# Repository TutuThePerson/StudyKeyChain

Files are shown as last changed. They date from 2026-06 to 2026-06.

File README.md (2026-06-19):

# Study Pal
A small-portable study companion that motivates you to study!!! (probably). Its purpose is to play voice clips (initially in my own voice lol, but you could ask your teacher's voice), it aims to run fixed focus session and reminds you to take a break and hyrdrate all in the formfactor of a keychain.

## Why did I build this?

No clue. jk. I just finished 2 months of A-levels and being grinding those past papers for atleast half a year now; I realise it is really demoralising to be studying 3 in the morning alone - so this idea stemmed from those experiences. It's just a bit of fun really and isn't aimed as a full replacement for regular discipline and proper revision but might provide that **little** push to keep studying while staying healthy. I didn't want a big, bulky solution so I thought it would be cool if I could fit it on a keychain, that I could hang on my bag as such.
The StudyPal consists of a 2 layer PCB, larger than a regular keycap but still small enough to put in your pocket or hang on your bag. It runs an ESP32-S3, with audio functionality (physically hidden under the keycap)

## Functions:

1. It goes through focus sessions on variable length via the rotary encoder under the keycap.
2. It has audio playback through a speaker which aims to play motivational audio clips, session start-end cues and hydration reminders.
3. OLED display which shows timer, session stats and break progress througha slim slanted window on the keycap.
4. Keycap - short press for motivational cue, long press to end a session early or to power off
5. Hidden Rotary Encoder undeer the keycap to adjust session length
6. Battery powered via a single-cell LiPo with USB C charging and ESD protection

### Schematic:

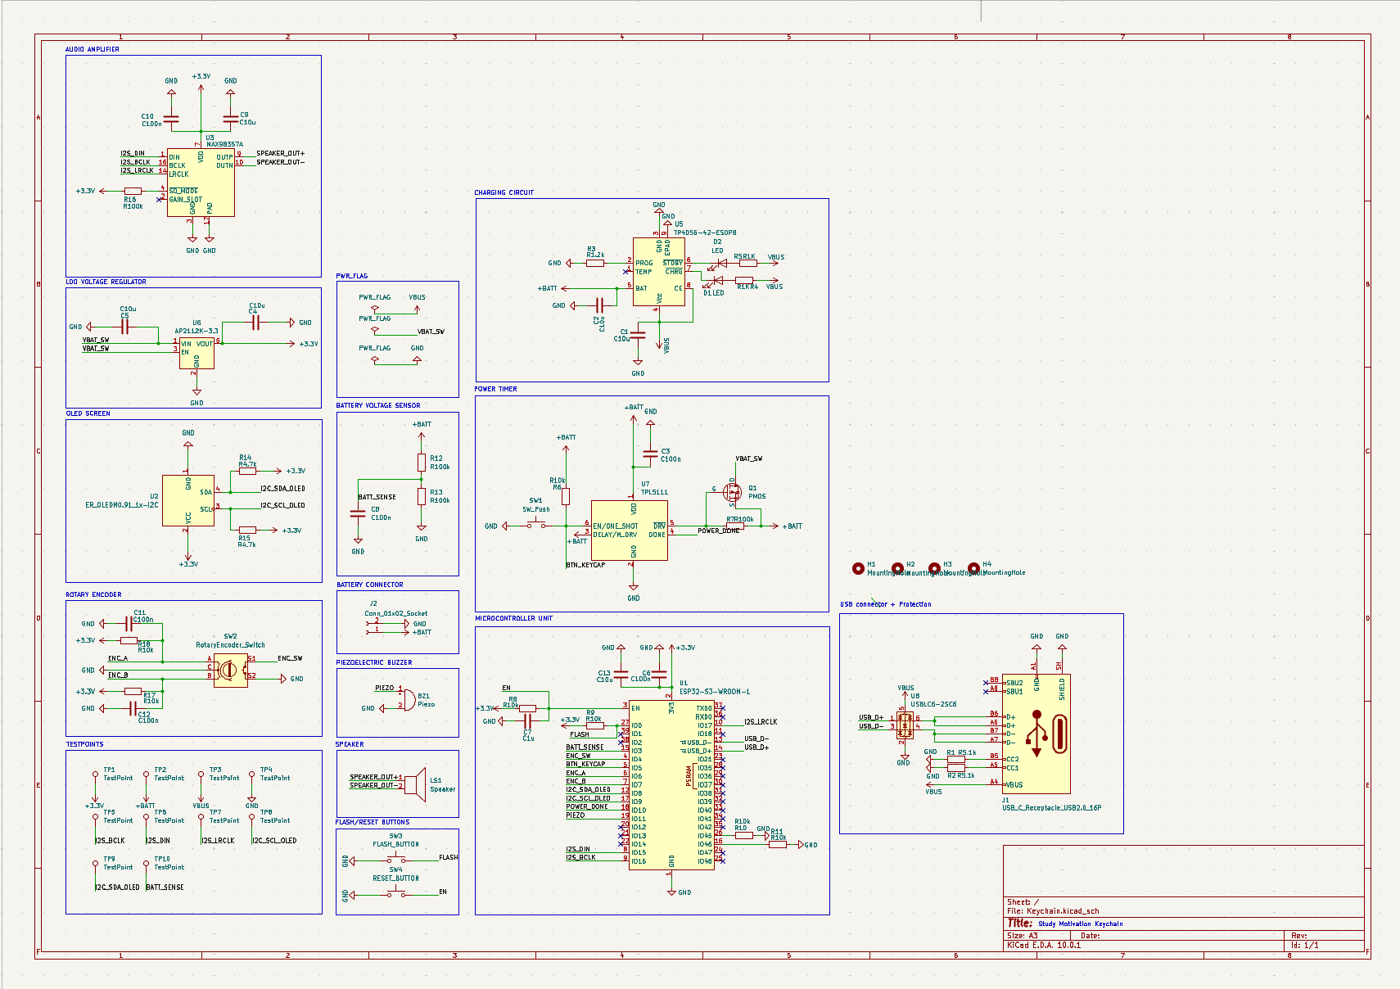
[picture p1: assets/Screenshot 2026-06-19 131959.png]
Schematic


### PCB:

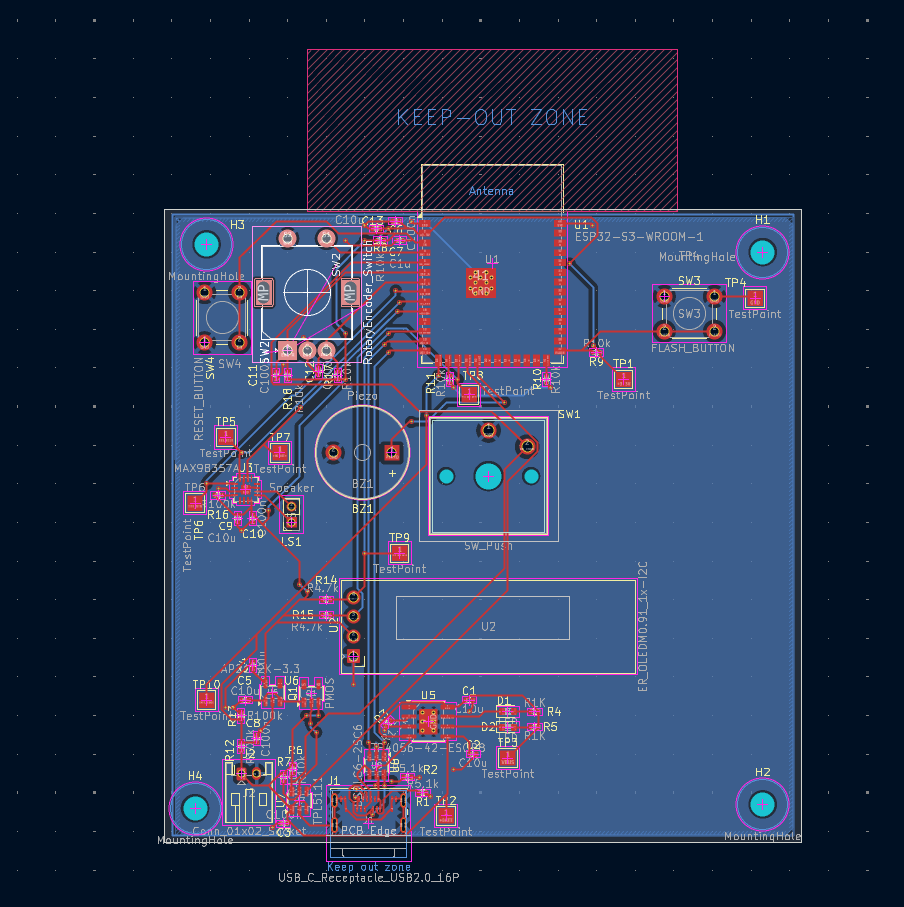
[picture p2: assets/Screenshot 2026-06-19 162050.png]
PCB kicad PCB

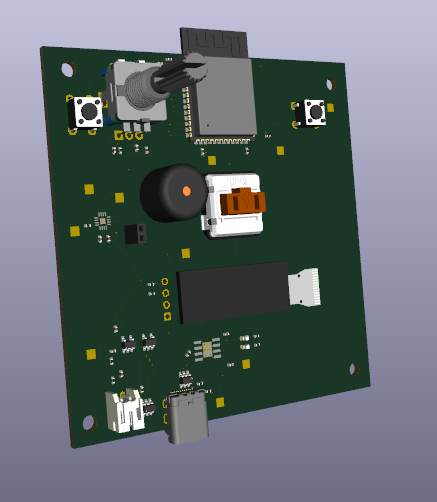
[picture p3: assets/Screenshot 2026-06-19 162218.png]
3D PCB kicad 3D RENDER PCB


### CASE:

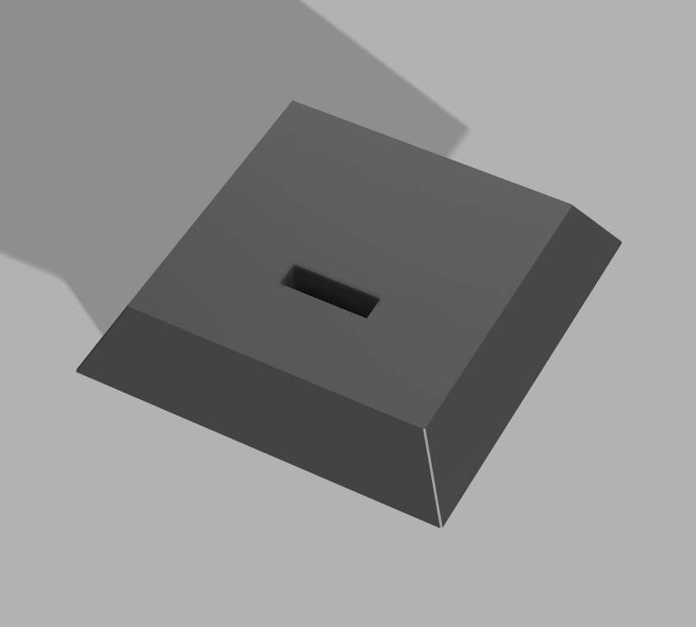
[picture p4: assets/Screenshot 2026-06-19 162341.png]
Assembled

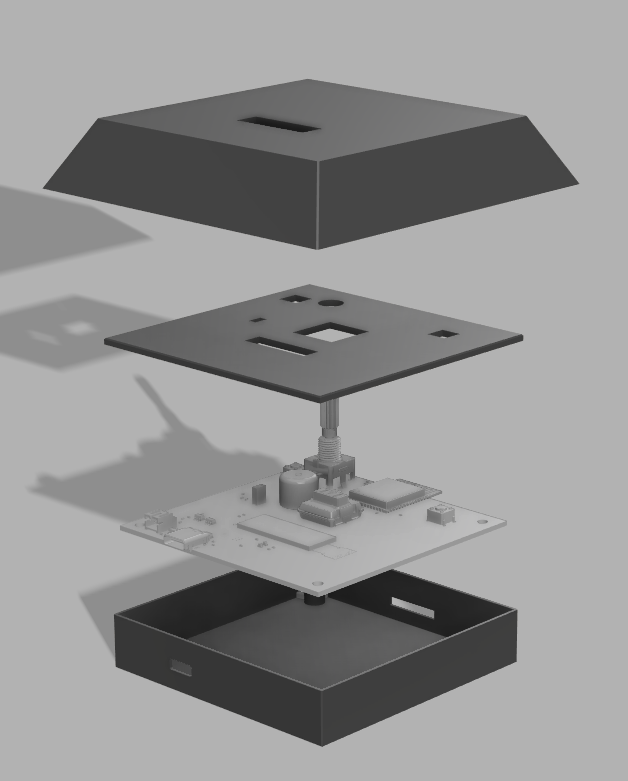
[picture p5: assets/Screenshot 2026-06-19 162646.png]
Exploded


### ZINE:

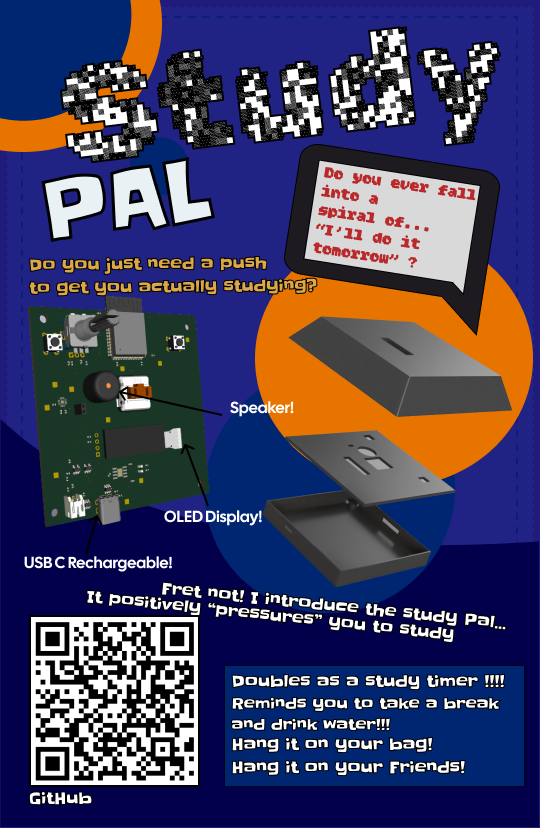
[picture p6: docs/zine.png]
Zine


## The Technical Stuff:

### Power sub-system:
 - USB-C in goes through TP4056 and manages LiPo charging at 1A (set by the 1200 ohm resistor). The charge status drives two LEDs where red = charging and green indicates fully charged/done. TPL5111 acts as a power switch by latching the AP2112k 3.3V LDO on when the user presses the Kalih  Choc Keycap, and cuts power when the firmware returns POWER_DONE.
 - A potential divider with 2 100k Ohm Resistor connectios is used to feed half the battery voltage so it can be read to monitor charge levels.

### Microcontroller unit
- ESP-32-S3-WROOM-1-N8, has 8 MB of flash, firmware and audio clips/message fit comfortably in the unit.
- The Strapping pins should be handled as stated by the datasheet.
   - GPIO0:10k pullup resistor and a flash button to GND
   - GPIO45/46: 10k pull down resistors to each pin
   - EN: 10k puullup with a 1 micro Farad Capacitor connected to ground in parallel.

### Audio:
- Audio is generated digitally by the microcontroller, and is streamed via I^2S to the class D amplifier, which in turn drives a speaked mounted under the keycap. Sound fires through the gapes just under the keycap edge.
- The amp's SD_MODE pin has a 100k ohm pullup to 3.3V, putting it in stereo mixed mono mode.

### Display: 
- 0.96" OLED breakouut connected via I^2C, viewed from a slim window cut into the case, meaning the display is stationary so it shouldn't be easily damaged.
- I^2C has 4.7k pullups to both SDA and SCL to 3.3V

### USB-C connector 
- 16 pin USB 2.0 receptable, D+ pads are tied together so directions works both ways - same goes for D- pads. These connections are then connected to the ESP32-S3's native USB pins. ESD protection is on both lines.

### PCB
- 2 layer
- L1 : components + signal traces
- L2 : ground pour and some signal traces

### Components:
1. ESP32-S3-WROOM-N8 MCU
2. TP4056 charging IC
3. TPL5111 power timer
4. AO3401 P-MOSFET
5. AP2122K - 3.3 LDO
6. MAX98357A audio amp
7. USBLC6-2SC6 ESD
8. USB-C connector 16-pin
9. 0.91" 128x32 SSD1306 OLED breakout
10. 28mm 8ohmn 2W speaker
11. 12mm piezo buzzer
12. Kalih Choc V1 Brown
13. EC11 Rotary Encoder
14. LiPo 803040 - 1000mah
15. Resistors (100k,10k,5.1k,4.7k,1.2k,1k - 0402)
16. Capacitors ( 100n,10u,1u = 0402)
17. LED (RED, GREEN - 0603)
18. 6mm tactile button
19. PCB
20. M3 self-tapping screws
21. 3D printed case + keycap

### BOM:
|No.|ITEM NAME|QUANTITY|UNIT PRICE|TOTAL PRICE|URL|
|-|-|-|-|-|-|
|1.|ESP32-S3-WROOM-1-N8|1|£4.21|£4.21|https://www.digikey.co.uk/en/products/detail/espressif-systems/ESP32-S3-WROOM-1-N8/15200089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|
|2.|TP4056 Charging IC|1|£1.00|£5.00 (pack of 5)|https://www.amazon.co.uk/TP4056-SOP-8-Chips-Battery-Charging-Black/dp/B0FKNDMF2P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|
|3.|TPL5111 power timer|1|£0.88|£0.88|https://www.digikey.co.uk/en/products/detail/texas-instruments/TPL5111DDCR/6572460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|
|4.|AO3401 P-MOSFET|1|£0.16|£0.16|https://www.digikey.co.uk/en/products/detail/umw/ao3401a/16705973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|
|5.|AP2112K-3.3 LDO|1|£0.19|£0.19|https://www.digikey.co.uk/en/products/detail/diodes-incorporated/AP2112K-3.3TRG1/4470746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|
|6.|MAX98357A AUDIO AMP|1|£2.77|£2.77|https://www.digikey.co.uk/en/products/detail/analog-devices-inc-maxim-integrated/max98357aete-t/4936122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|
|7.|USBLC6-2SC6 ESD|1|£0.33|£0.33|https://www.digikey.co.uk/en/products/detail/analog-devices-inc-maxim-integrated/max98357aete-t/4936122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|
|8.|USB-C connector 16 pin|1|£1.65|£1.65|https://www.digikey.co.uk/en/products/detail/amphenol-cs-commercial-products/124019772112A/13683231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|
|9.|0.96" SSD1306 OLED BREAKOUT|1|£1.49|£1.49|https://www.aliexpress.com/item/1005006782987637.html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|
|10.|28mm 8OHM 2W speaker|1|£0.17|£0.99 (pack of 6|https://www.aliexpress.com/item/1005011990029265.html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|
|11.|12mm PIEZO BUZZER|1|£0.05|£0.99 (pack of 20)|https://www.aliexpress.com/item/1005009235440867.html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|
|12.|Kalih Choc V1|1|£0.35|£3.48( pack of 10)|https://www.aliexpress.com/item/1005011812362132.html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|
|13.|EC11 Rotary Encoder|1|£0.90|£0.90|https://www.aliexpress.com/item/1005007644083514.html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|
|14.|LiPo 803040 -1000mah|1|£3.79|£3.79|https://www.aliexpress.com/item/1005011940576057.html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|
|15.| Resistor 100k|4|£0.07|£0.28|https://www.digikey.co.uk/en/products/detail/yageo/RC0402FR-07100KL/726526|
|16.| Resistor 10k| 7|£0.07|£0.49|https://www.digikey.co.uk/en/products/detail/yageo/RC0402FR-0710KL/726523|
|17.| Resistor 5.1k|2|£0.07|£0.14|https://www.digikey.co.uk/en/products/detail/yageo/RC0402FR-075KL/5917711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|
|18.| Resistor 4.7k|2|£0.07|£0.14|https://www.digikey.co.uk/en/products/detail/yageo/RC0402FR-074K7L/2827563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|
|19.| Resistor 1.2k|1|£0.07|£0.07|https://www.digikey.co.uk/en/products/detail/yageo/RC0402FR-071K2L/726517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|
|20.| Resistor 1k|2|£0.07|£0.14|https://www.digikey.co.uk/en/products/detail/yageo/RC0402FR-071KL/726513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|
|21.| Capacitor 10u|6|£0.27|£1.62|https://www.digikey.co.uk/en/products/detail/murata-electronics/GRM155R61A106ME18D/26264983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|
|22.| Capacitor 1u|1|£0.07|£0.07|https://www.digikey.co.uk/en/products/detail/taiyo-yuden/JMK105BJ105KV-F/930583|
|23.| Capacitor 100n|6|£0.07|£0.42|https://www.digikey.co.uk/en/products/detail/samsung-electro-mechanics/CL05B104KP5NNNC/3886660|
|24.| LED RED|1|£0.34|£0.34|https://www.digikey.co.uk/en/products/detail/lumex-opto-components-inc/SML-LXFM0603SIC-TR/411897|
|25.| LED GREEN|1|£0.25|£0.25|https://www.digikey.co.uk/en/products/detail/w%C3%BCrth-elektronik/150060GS73220/8557160|
|26.| 6mm Tactile Button|2|£0.87|£1.74|https://www.digikey.co.uk/en/products/detail/omron-electronics-inc-emc-div/B3U-1100P/1534339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|
|27.|PCB|1|£0.48|£2.4|JLCPCB|
|28.|Solder Paste Stencil|1|£5.37|£5.37|JLCPCB|
|29.|M3 Self Tapping Screws|4|£0.05|£2.47(50pack)|https://cpc.farnell.com/unbranded/m3x6-pan-pozi-stainl/m3x6-pan-pozi-stainless-screws/dp/FN00814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|pcrid|426684131423|kword||match||plid||slid||product|FN00814|pgrid|100371162718|ptaid|pla-2177230439981|&CMP=KNC-GUK-CPC-SHOPPING-9262013734-100371162718-FN00814&s_kwcid=AL!5616!3!426684131423!!!network}!2177230439981!&gad_source=1&gad_campaignid=9262013734&gbraid=0AAAAAD_m6B18mbvSishqdH_AlczsMH5Ge&gclid=CjwKCAjw0dPRBhAPEiwAE5vTToLz2cqZ-4VV0NWd0TadiM0KJ0ZQb9aNZPIKNwyf5dgqHOcgOcoShBoCqskQAvD_BwE
|30.|3D printed Case and Keycap|1 set|N/A (small)|£10.50 (1 Roll PETG HF)|https://uk.store.bambulab.com/products/petg-hf?id=42010450264124|
|31.|Thin Wire|1|~£0.5 (1m)|£4.99 (spool of 10m)|https://www.amazon.co.uk/sourcing-map-Stranded-Electrical-Connecting/dp/B0F6LRFJS6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|
|32.|Keychain|1|£0.13|£3.89 (pack of 30)|https://www.amazon.co.uk/YHYZ-Premium-Keychain-Suitable-Jewelry/dp/B08CMWFL8Y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|
-
### Assembly:
 - Make sure you have all components listed available and casing 3D printed.
 - Solder all the components on the PCB as per the schematic
 - Connect the battery to the 2 pin connector (label in schematic file)
 - Place the PCB on top of the base and use M3 screws, preferably around 3-4mm
 - Flash firmware onto the ESP32 using the USB-C connector (If there is no output when flashing, hold the flash button to reset - forces chip into download mode)
 - Use plastic adhesive to adhere the the lid to the base - once everything works okay
 - Put on the keycap and enjoy!

### Design Notes:
- You could go with a different mcu but I chose the ESP-32 as this one has native USB, decent peripheral support and has 8MB of memory which makes it a suitable cost-effective solution in this case. The atenna is not used, but it could be used in future alterations with firmware but if you really wanted bluetooth or wifi you can use ur phone lol
- I reccomend you get a stencil which would make soldering alot easier
- The system switches and the rotary encoder is located under the keycap as they are designed to be set-once parameters, not designed to be constantly adjusted so this would make the keycap look better.

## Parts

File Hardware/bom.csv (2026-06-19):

No | ITEM NAME | QUANTITY | UNIT PRICE | TOTAL PRICE
1 | ESP32-S3-WROOM-1-N8 | 1 | £4.21 | £4.21
2 | TP4056 | Charging IC | 1 | £1.00 | £5.00
3 | TPL5111 power timer | 1 | £0.88 | £0.88
4 | AO3401 P-MOSFET | 1 | £0.16 | £0.16
5 | AP2112K-3.3 LDO | 1 | £0.19 | £0.19
6 | MAX98357A AUDIO AMP | 1 | £2.77 | £2.77
7 | USBLC6-2SC6 ESD | 1 | £0.33 | £0.33
8 | USB-C connector 16 pin | 1 | £1.65 | £1.65
9 | 0.96" SSD1306 OLED BREAKOUT | 1 | £1.49 | £1.49
10 | 28mm 8OHM 2W speaker | 1 | £0.17 | £0.99
11 | 12mm PIEZO BUZZER | 1 | £0.05 | £0.99
12 | Kalih Choc V1 | 1 | £0.35 | £3.48
13 | EC11 Rotary Encoder | 1 | £0.90 | £0.90
14 | LiPo 803040 -1000mah | 1 | £3.79 | £3.79
15 | Resistor 100k | 1 | £0.07 | £0.28
16 | Resistor 10k | 7 | £0.07 | £0.49
17 | Resistor 5.1k | 2 | £0.07 | £0.14
18 | Resistor 4.7k | 2 | £0.07 | £0.14
19 | Resistor 1.2k | 1 | £0.07 | £0.07
20 | Resistor 1k | 2 | £0.07 | £0.14
21 | Capacitor 10u | 6 | £0.27 | £1.62
22 | Capacitor 1u | 1 | £0.07 | £0.07
23 | Capacitor 100n | 6 | £0.07 | £0.42
24 | LED RED | 1 | £0.34 | £0.34
25 | LED GREEN | 1 | £0.25 | £0.25
26 | 6mm Tactile Button | 2 | £0.87 | £1.74
27 | PCB | 1 | £0.48 | £2.40
28 | Solder Paste Stencil | 1 | £5.37 | £5.37
29 | M3 Self Tapping Screws | 4 | £0.05 | £2.47
30 | 3D printed Case and Keycap | 1 | setn/a (small) | £10.50
31 | Thin Wire | 1 | ~£0.5 | £4.99
32 | Keychain | 1 | £0.13 | £3.89

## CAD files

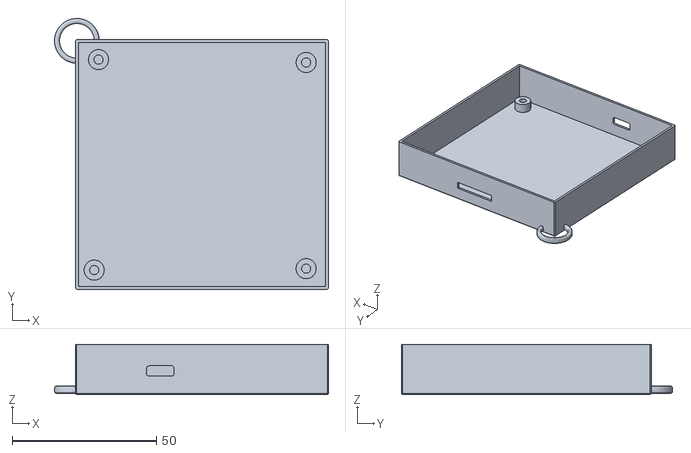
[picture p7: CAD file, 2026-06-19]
Case/main_case_body.stl
95.0 x 94.0 x 17.5

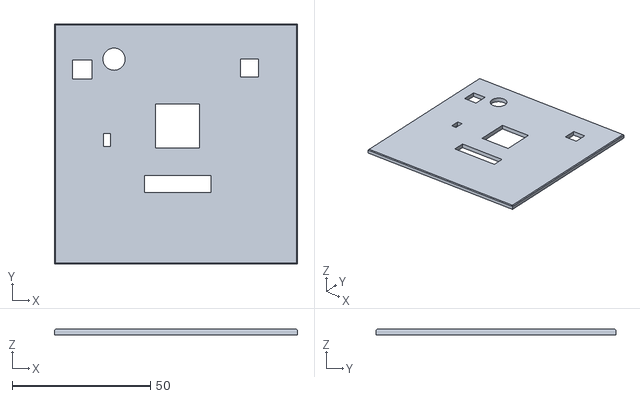
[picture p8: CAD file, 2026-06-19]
Case/main_body_lid.stl
87.7 x 86.7 x 2.00

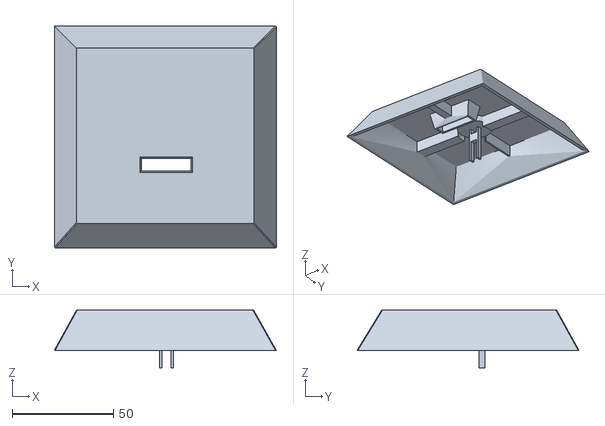
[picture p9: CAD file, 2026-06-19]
Case/keycap.stl
109.8 x 110.0 x 28.5

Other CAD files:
Case/Keychain_Casing_Source.f3d

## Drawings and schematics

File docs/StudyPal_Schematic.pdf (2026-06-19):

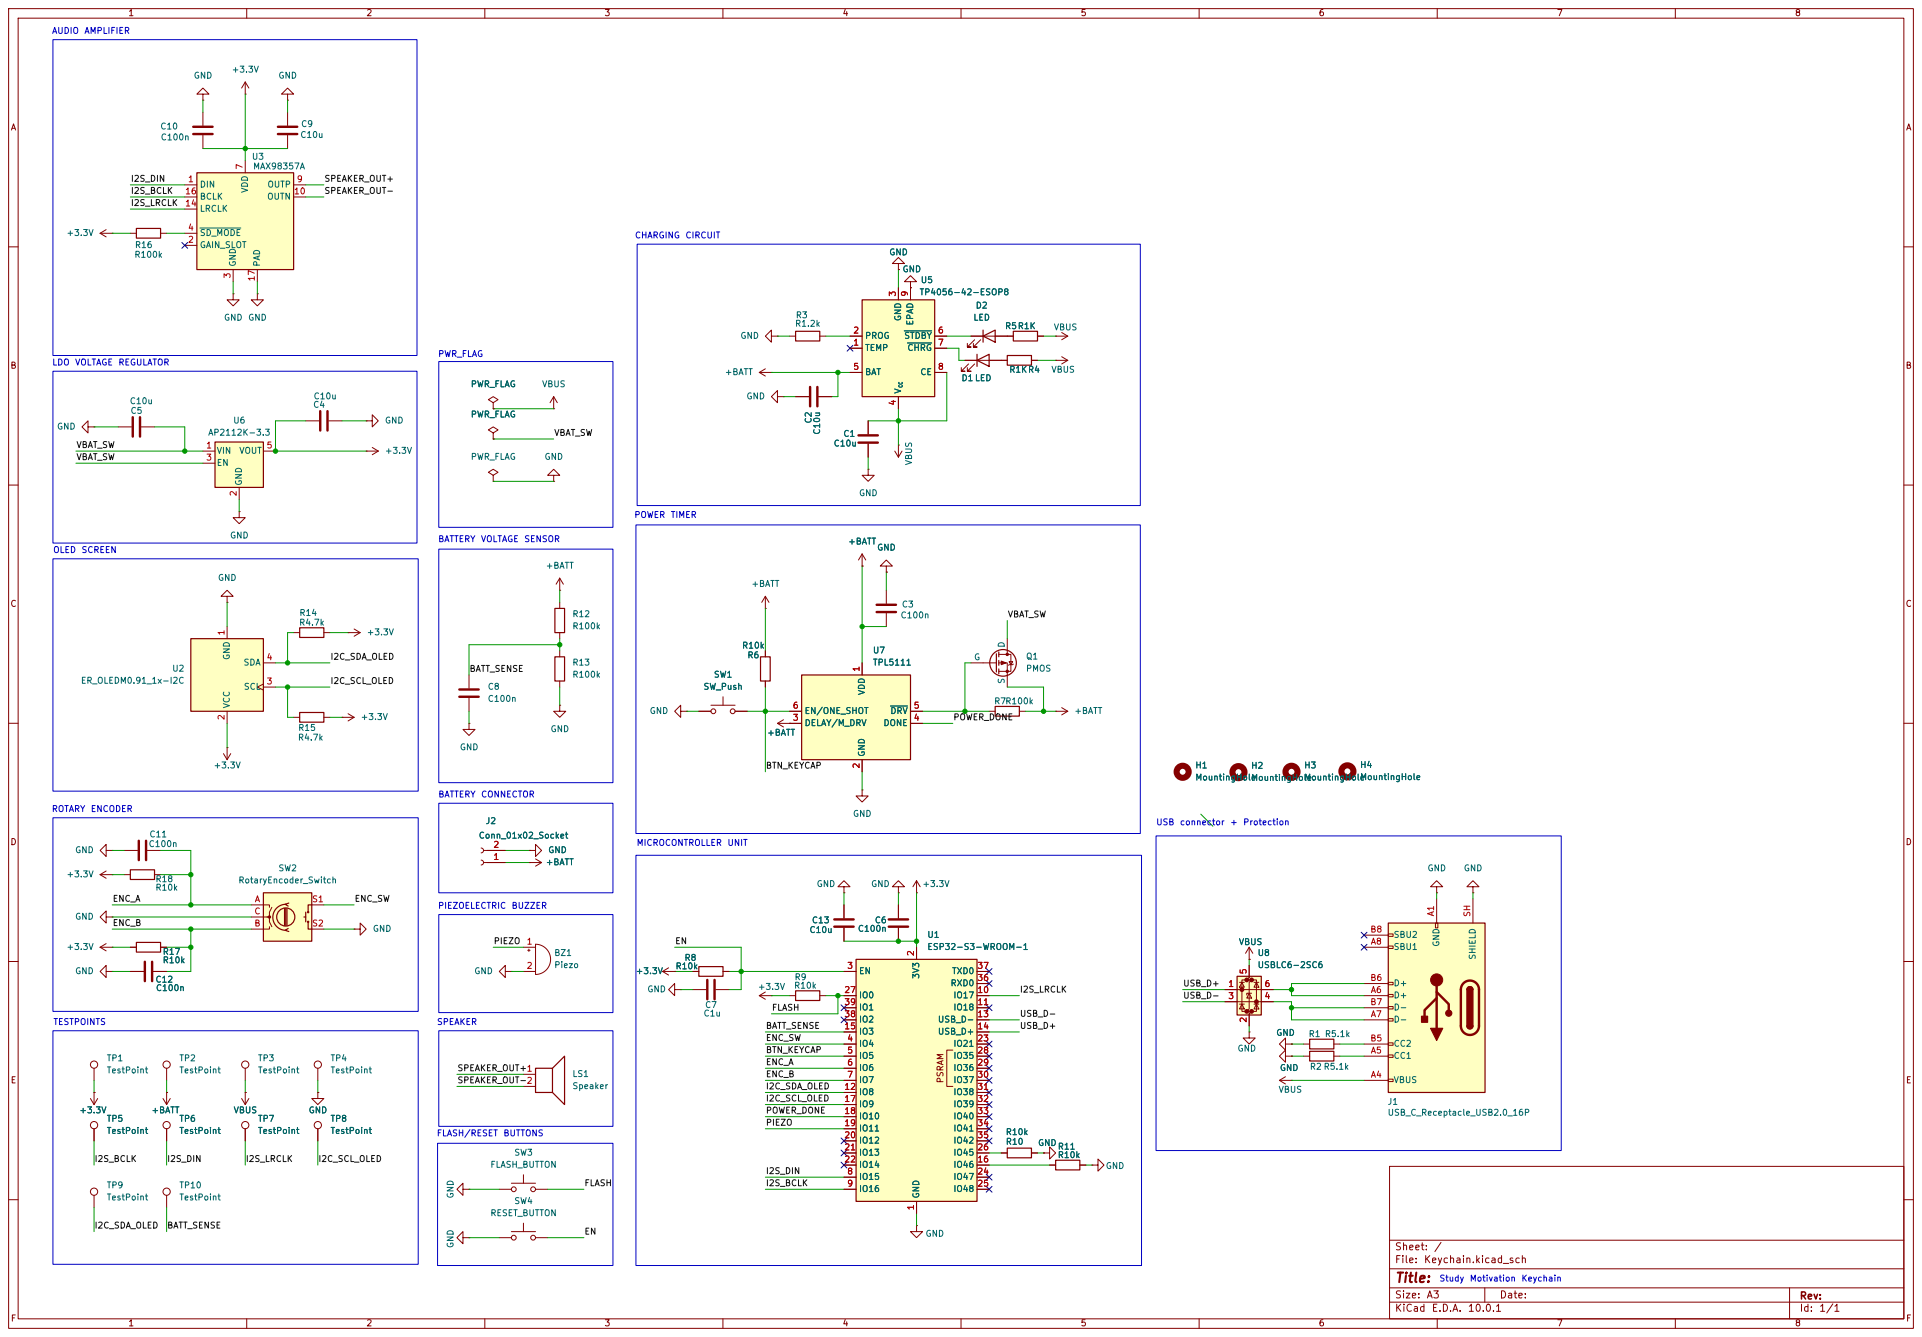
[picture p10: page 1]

LDO VOLTAGE REGULATOR OLED SCREEN

PIEZO

VBUS A4 CC1 A5 D+ A6 D- A7

Size: A3 | Rev:
KiCad E.D.A. 10.0.1 | Id: 1/1

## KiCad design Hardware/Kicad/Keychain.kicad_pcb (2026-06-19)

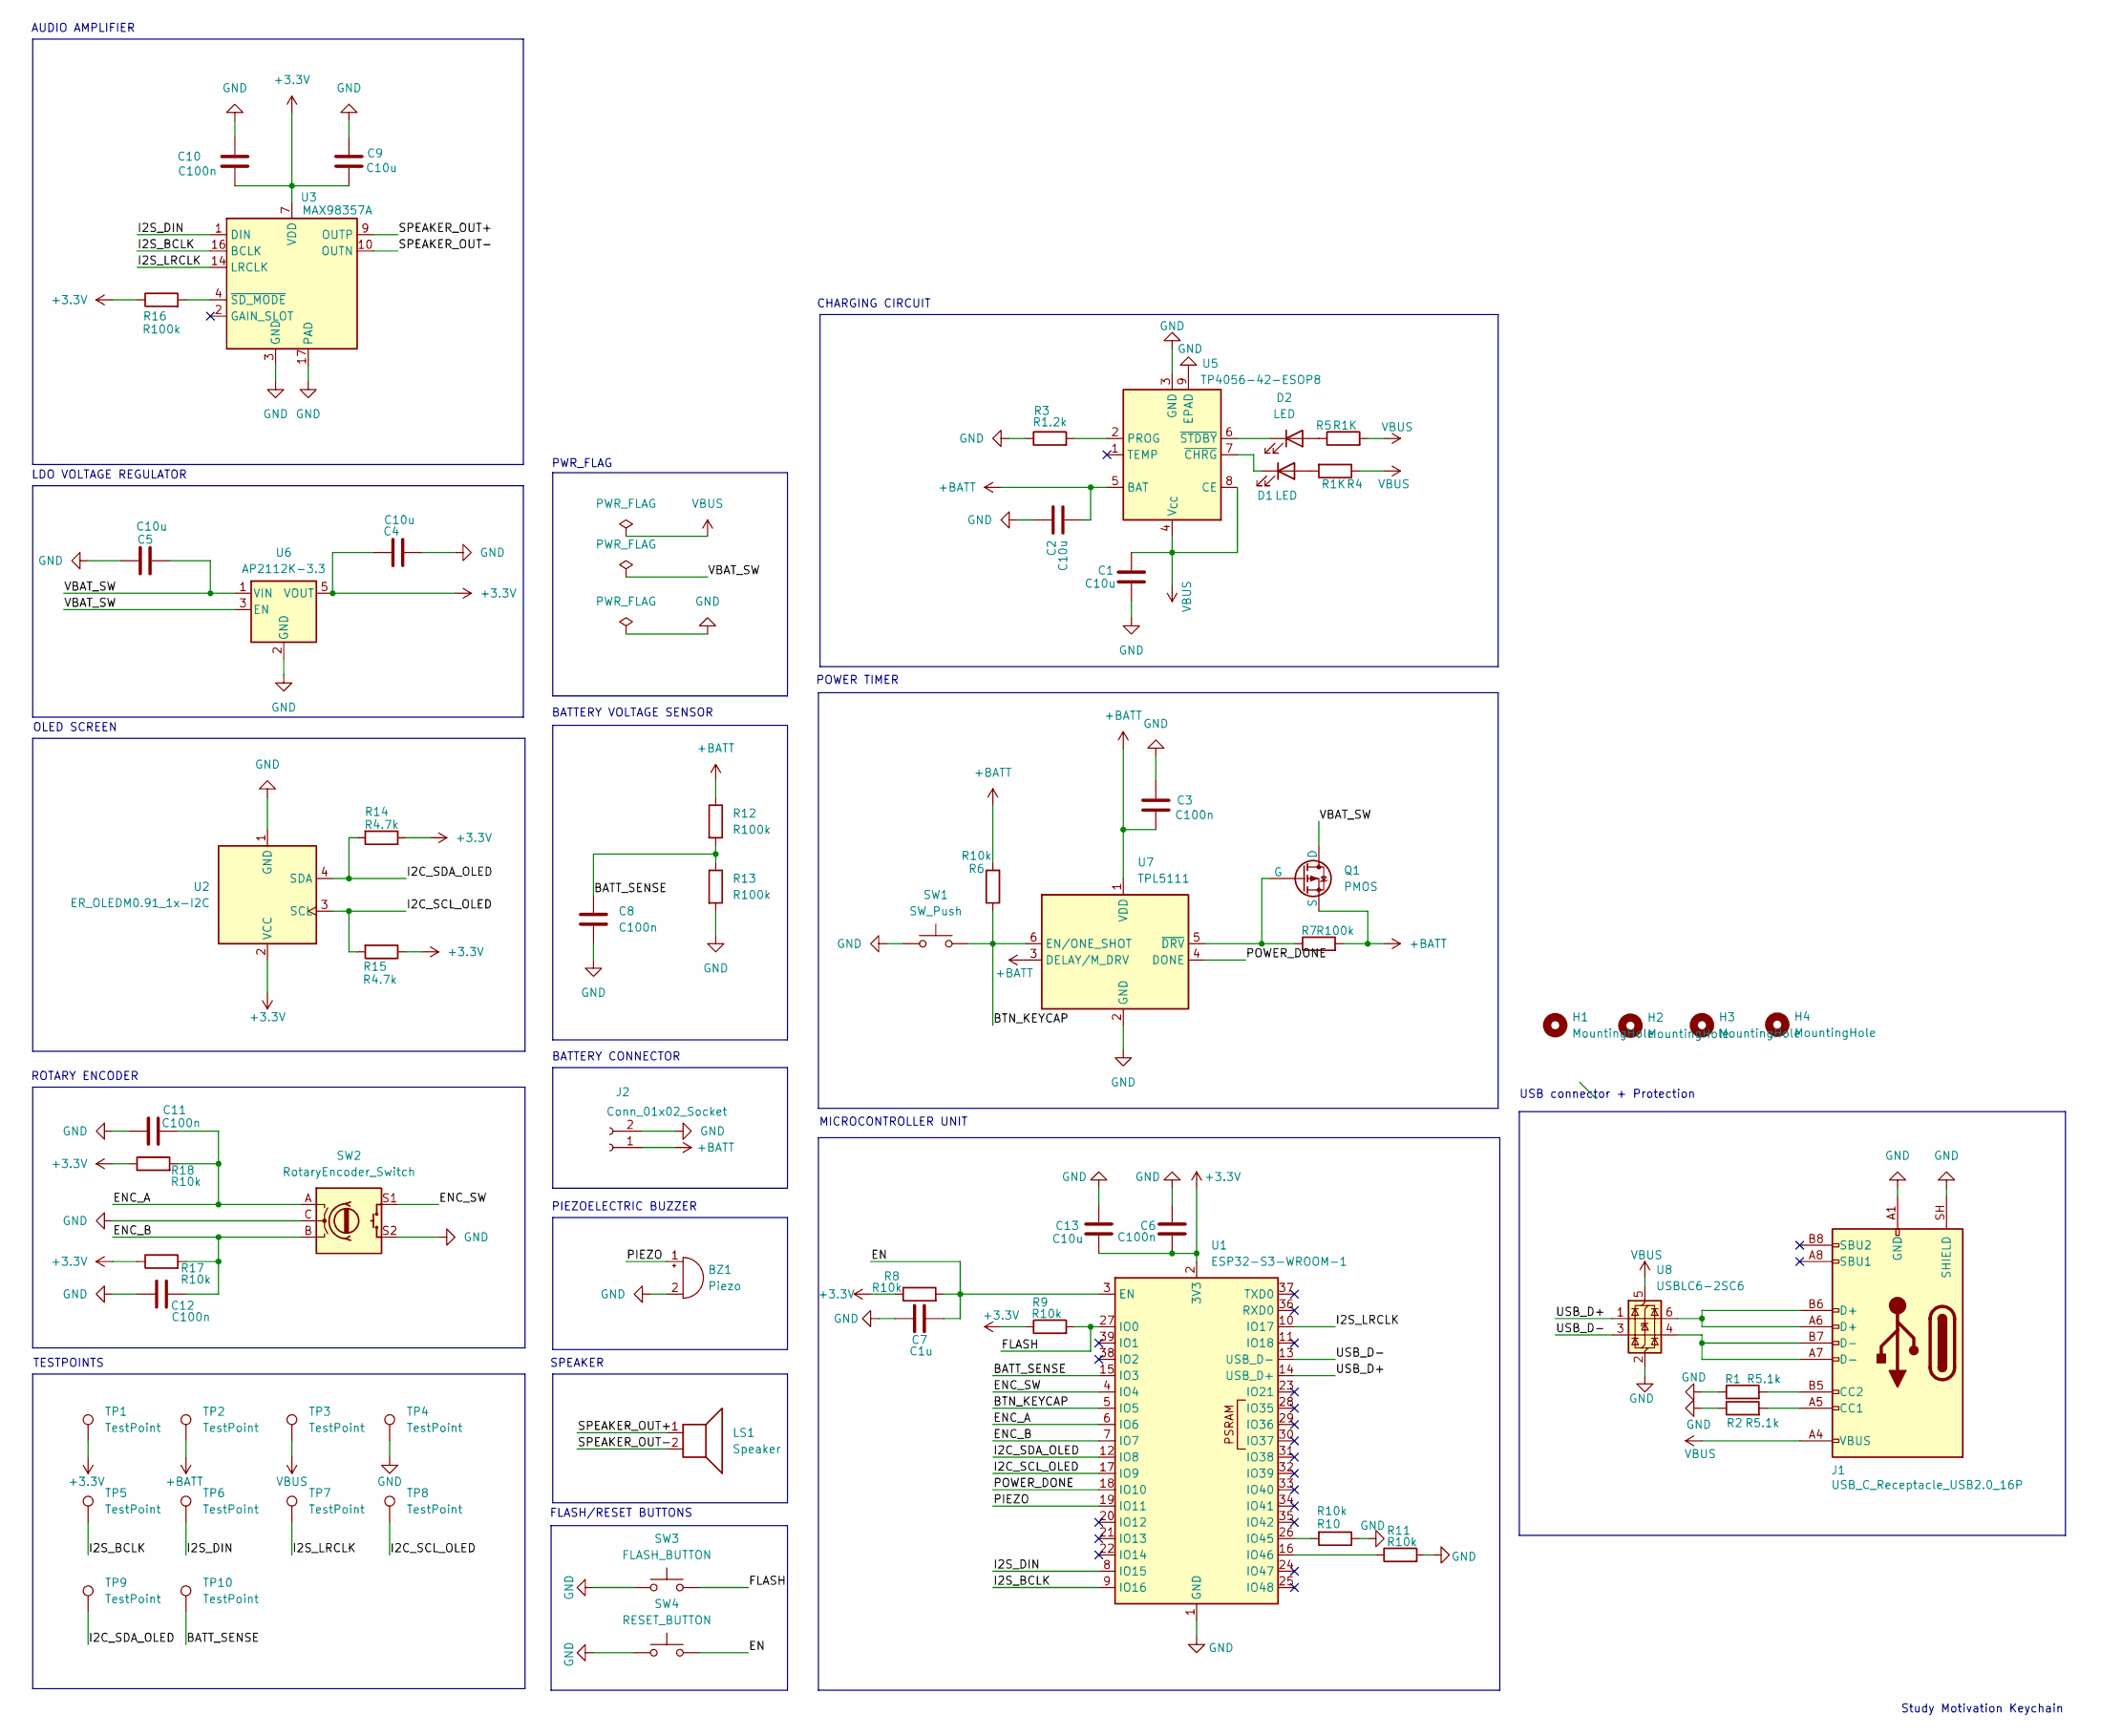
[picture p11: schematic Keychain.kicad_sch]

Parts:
BZ1: Piezo; Buzzer_12x9.5RM7.6
C1, C2, C4, C5, C9, C13: C10u; C_0402_1005Metric
C3, C6, C8, C10, C11, C12: C100n; C_0402_1005Metric
C7: C1u; C_0402_1005Metric
D1, D2: LED; LED_0603_1608Metric
H1, H2, H3, H4: MountingHole; MountingHole_3.2mm_M3
J1: USB_C_Receptacle_USB2.0_16P; USB_C_Receptacle_Amphenol_124019772112A
J2: Conn_01x02_Socket; JST_PH_S2B-PH-K_1x02_P2.00mm_Horizontal
LS1: Speaker; PinSocket_1x02_P2.00mm_Vertical
Q1: PMOS; SOT-23-5
R1, R2: R5.1k; R_0402_1005Metric
R3: R1.2k; R_0402_1005Metric
R4, R5: R1K; R_0402_1005Metric
R6, R8, R9, R10, R11, R17, R18: R10k; R_0402_1005Metric
R7, R12, R13, R16: R100k; R_0402_1005Metric
R14, R15: R4.7k; R_0402_1005Metric
SW1: SW_Push; SW_Kailh_Choc_V1_1.00u
SW2: RotaryEncoder_Switch; RotaryEncoder_Alps_EC11E-Switch_Vertical_H20mm
SW3: FLASH_BUTTON; SW_PUSH_6mm
SW4: RESET_BUTTON; SW_PUSH_6mm
TP1, TP2, TP3, TP4, TP5, TP6, TP7, TP8, TP9, TP10: TestPoint; TestPoint_Pad_2.0x2.0mm
U1: ESP32-S3-WROOM-1
U2: ER_OLEDM0.91_1x-I2C
U3: MAX98357A; TQFN-16-1EP_3x3mm_P0.5mm_EP1.23x1.23mm
U5: TP4056-42-ESOP8; SOIC-8-1EP_3.9x4.9mm_P1.27mm_EP2.41x3.3mm_ThermalVias
U6: AP2112K-3.3; SOT-23-5
U7: TPL5111; SOT-23-6
U8: USBLC6-2SC6; SOT-23-6

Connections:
+3.3V: C4.1, C6.1, C9.2, C10.2, C13.1, R8.1, R9.1, R14.1, R15.1, R16.1, R17.1, R18.1, TP1.1 (1_1), U1.2 (3V3), U2.2 (VCC), U3.7 (VDD), U3.8 (VDD), U6.5 (VOUT)
+BATT: C2.1, C3.1, J2.1, Q1.3 (S), R6.2, R7.2, R12.1, TP2.1 (1_1), U5.5 (BAT), U7.1 (VDD), U7.3 (DELAY/M_DRV)
/<NO NET>: TP7.1 (1_1), U1.10 (IO17), U3.14 (LRCLK)
/BATT_SENSE: C8.1, R12.2, R13.1, TP10.1 (1_1), U1.15 (IO3)
/BTN_KEYCAP: R6.1, SW1.2, U1.5 (IO5), U7.6 (EN/ONE_SHOT)
/EN: C7.2, R8.2, SW4.2, U1.3 (EN)
/ENC_A: C11.2, R18.2, SW2.A, U1.6 (IO6)
/ENC_B: C12.2, R17.2, SW2.B, U1.7 (IO7)
/ENC_SW: SW2.S1, U1.4 (IO4)
/FLASH: R9.2, SW3.2, U1.27 (IO0)
/I2C_SCL_OLED: R15.2, TP8.1 (1_1), U1.17 (IO9), U2.3 (SCL)
/I2C_SDA_OLED: R14.2, TP9.1 (1_1), U1.12 (IO8), U2.4 (SDA)
/I2S_BCLK: TP5.1 (1_1), U1.9 (IO16), U3.16 (BCLK)
/I2S_DIN: TP6.1 (1_1), U1.8 (IO15), U3.1 (DIN)
/PIEZO: BZ1.1 (+), U1.19 (IO11)
/POWER_DONE: U1.18 (IO10), U7.4 (DONE)
/SPEAKER_OUT+: LS1.1, U3.9 (OUTP)
/SPEAKER_OUT-: LS1.2, U3.10 (OUTN)
/USB_D+: U1.14 (USB_D+), U8.1 (I/O1)
/USB_D-: U1.13 (USB_D-), U8.3 (I/O2)
/VBAT_SW: C5.1, Q1.1 (D), U6.1 (VIN), U6.3 (EN)
GND: BZ1.2 (-), C1.2, C2.2, C3.2, C4.2, C5.2, C6.2, C7.1, C8.2, C9.1, C10.1, C11.1, C12.1, C13.2, J1.A1 (GND), J1.A12 (GND), J1.B1 (GND), J1.B12 (GND), J1.SH (SHIELD), J2.2, R1.1, R2.1, R3.1, R10.1, R11.2, R13.2, SW1.1, SW2.C, SW2.S2, SW3.1, SW4.1, TP4.1 (1_1), U1.1 (GND), U1.40 (GND), U1.41 (GND), U2.1 (GND), U3.3 (GND), U3.11 (GND), U3.15 (GND), U3.17 (PAD), U5.3 (GND), U5.9 (EPAD), U6.2 (GND), U7.2 (GND), U8.2 (GND)
unnamed: D1.2 (A), R4.2
unnamed: D1.1 (K), U5.7 (~CHRG)
unnamed: D2.2 (A), R5.1
unnamed: D2.1 (K), U5.6 (~STDBY)
unnamed: J1.A5 (CC1), R2.2
unnamed: J1.B5 (CC2), R1.2
unnamed: J1.A6 (D+), J1.B6 (D+), U8.6 (I/O1)
unnamed: J1.A7 (D-), J1.B7 (D-), U8.4 (I/O2)
unnamed: Q1.2 (G), R7.1, U7.5 (~DRV)
unnamed: R10.2, U1.26 (IO45)
unnamed: R11.1, U1.16 (IO46)
unnamed: R16.2, U3.4 (~SD_MODE)
unnamed: R3.2, U5.2 (PROG)
VBUS: C1.1, J1.A4 (VBUS), J1.A9 (VBUS), J1.B4 (VBUS), J1.B9 (VBUS), R4.1, R5.2, TP3.1 (1_1), U5.4 (V_{CC}), U5.8 (CE), U8.5 (VBUS)

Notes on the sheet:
LDO VOLTAGE REGULATOR
TESTPOINTS
ROTARY ENCODER
POWER TIMER
MICROCONTROLLER UNIT
PIEZOELECTRIC BUZZER
BATTERY CONNECTOR
SPEAKER
FLASH/RESET BUTTONS
Study Motivation Keychain
PWR_FLAG
AUDIO AMPLIFIER
BATTERY VOLTAGE SENSOR
OLED SCREEN
CHARGING CIRCUIT
USB connector + Protection

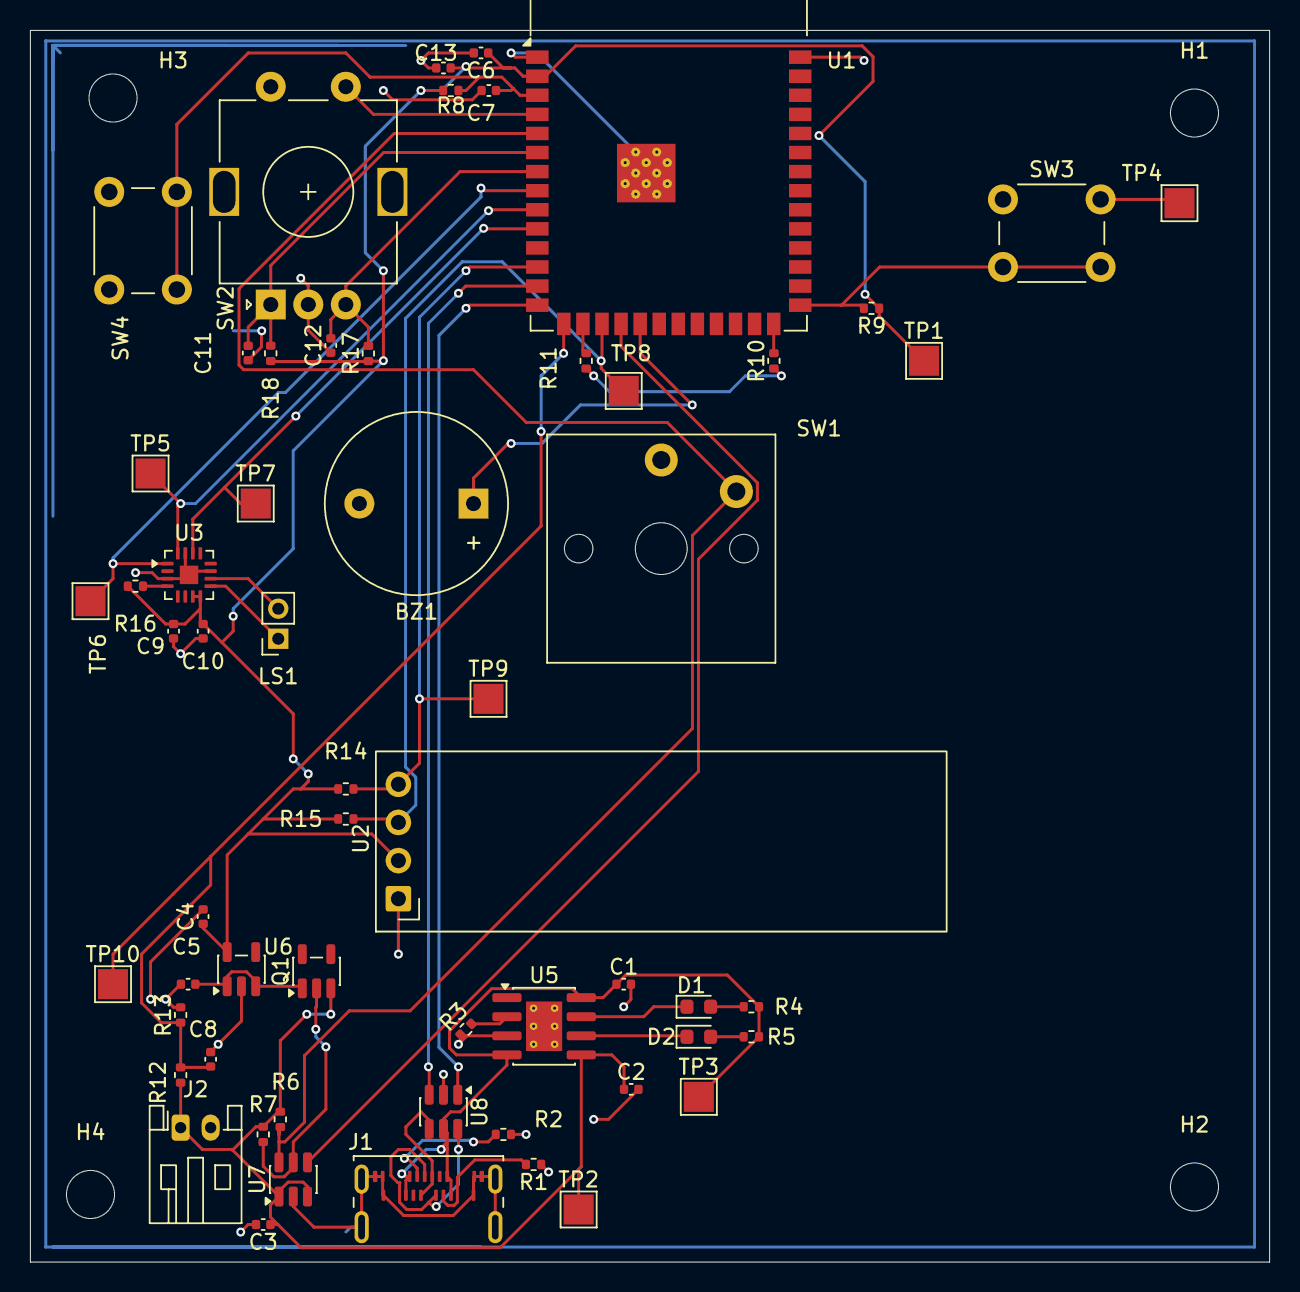
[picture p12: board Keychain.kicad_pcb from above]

Board: 2 copper layers, 82.5 x 82.0 mm, 63 parts (0 on the bottom side), 36 nets.

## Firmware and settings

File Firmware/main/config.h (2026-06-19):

#pragma once

//#############
// This file contains the pin assignments for the study keychain project
//#############

// Button (Kalih Choc Switch)
#define PIN_BUTTON 5

// Rotary encoder
#define PIN_ENCODER_A 6
#define PIN_ENCODER_B 7
#define PIN_ENCODER_SW 4 

//I^2C (Oled Display)
#define PIN_i2C_SDA 12
#define PIN_i2C_SCL 17
#define I2C_FREQ_HZ 400000
#define OLED_ADDRESS 0x3C

// I^2S (audio amplifier)
#define PIN_I2S_DIN 8
#define PIN_I2S_BCLK 9
#define PIN_I2S_LRCLK 10

// Piezoelectric (audio feedback)
#define PIN_PIEZO 11

// Power Management 
#define PIN_POWER_DONE 18
#define PIN_BATTERY_SENS 15

//#############
//constants
//#############

//Study Session Duration (fixed)

#define SESSION_DEFAULT_SECONDS 3300
#define BREAK_DURATION_SECONDS 300

//Reminder

#define HYDRATION_REMINDER_SECONDS 3300

// Battery Monitoring
#define POTENTIAL_DIVIDER_RATIO 2.0f 
#define FULL_BATT_mV 4200
#define BATT_EMPTY_mV 3000
#define BATT_LOW_mV 3300

// Audio 
#define I2S_SAMPLE_RATE 16000 
#define I2S_BUFFER_SIZE 1024

// other UI/timing
#define IDLE_TIMEOUT_mS 30000
#define POWER_OFF_TIMEOUT_mS 14400000
#define LONG_PRESS_mS 2000
#define DEBOUNCE_mS 30

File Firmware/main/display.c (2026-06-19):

#include "display.h"
#include "config.h"
#include "driver/i2c.h"
#include "esp_log.h"
#include "freertos/FreeRTOS.h"
#include "freertos/task.h"
#include <string.h>
#include <stdio.h>
#include "font8x8.h"

static const char *TAG = "DISPLAY";

#define DISPLAY_OFF 0xAE
#define DISPLAY_ON 0xAF
#define SET_PAGE 0xB0
#define SET_COL_LOW 0x00
#define SET_COL_HIGH 0x10
#define DISPLAY_WIDTH 128
#define DISPLAY_HEIGHT 32
#define DISPLAY_PAGES (DISPLAY_HEIGHT/8)

static uint8_t framebuffer[DISPLAY_WIDTH*DISPLAY_HEIGHT];

static esp_err_t send_command(uint8_t cmd) {
    i2c_cmd_handle_t handle = i2c_cmd_link_create();
    i2c_master_start(handle);
    i2c_master_write_byte(handle, (OLED_ADDRESS << 1 )| I2C_MASTER_WRITE, true);
    i2c_master_write_byte(handle, 0x00, true);
    i2c_master_write_byte(handle, cmd, true);
    i2c_master_stop(handle);
    esp_err_t ret = i2c_master_cmd_begin(I2C_NUM_0, handle, 1000 / portTICK_PERIOD_MS);
    i2c_cmd_link_delete(handle);
    return ret;
}

static esp_err_t send_data(const uint8_t *data, size_t len) {
    i2c_cmd_handle_t handle = i2c_cmd_link_create();
    i2c_master_start(handle);
    i2c_master_write_byte(handle, (OLED_ADDRESS << 1)| I2C_MASTER_WRITE, true);
    i2c_master_write_byte(handle, 0x40, true);
    i2c_master_write(handle, data, len, true);
    i2c_master_stop(handle);
    esp_err_t ret = i2c_master_cmd_begin(I2C_NUM_0, handle, 1000 / portTICK_PERIOD_MS);
    i2c_cmd_link_delete(handle);
    return ret;
}

void display_init(void) {
    i2c_config_t conf = {
        .mode = I2C_MODE_MASTER,
        .sda_io_num = PIN_i2C_SDA,
        .scl_io_num = PIN_i2C_SCL,
        .sda_pullup_en = GPIO_PULLUP_ENABLE,
        .scl_pullup_en = GPIO_PULLUP_ENABLE,
        .master.clk_speed = I2C_FREQ_HZ,
    };
    i2c_param_config(I2C_NUM_0, &conf);
    i2c_driver_install(I2C_NUM_0, I2C_MODE_MASTER, 0, 0, 0);
    send_command(DISPLAY_OFF);
    send_command(0xD5); send_command(0x80);
    send_command(0xA8); send_command(0x1F);
    send_command(0xD3); send_command(0x00);
    send_command(0x40);
    send_command(0x8D); send_command(0x14);
    send_command(0x20); send_command(0x00);
    send_command(0xA1);
    send_command(0xC8);
    send_command(0xDA); send_command(0x02);
    send_command(0x81); send_command(0x8F);
    send_command(0xD9); send_command(0xF1);
    send_command(0xDB); send_command(0x40);
    send_command(0xA4);
    send_command(0xA6);
    send_command(DISPLAY_ON);
    memset(framebuffer, 0, sizeof(framebuffer));
    display_refresh();
    ESP_LOGI(TAG, "Display initialised");
}
void display_clear(void) {
    memset(framebuffer, 0, sizeof(framebuffer));
}
void display_refresh(void) {
    uint8_t page = 0;
    for (uint8_t page = 0; page < DISPLAY_PAGES; page++) {
       send_command(SET_PAGE | page);
       send_command(SET_COL_LOW | 0x0);
       send_command(SET_COL_HIGH | 0x0);
       send_data(&framebuffer[page * DISPLAY_WIDTH],DISPLAY_WIDTH); 
    }

}

static void draw_char(int x, int y, char c) {
 if (c <0x20 || c > 0x7E) c = '?';
 int idx = c - 0x20;
 int page =( y / 8);
 if (page < 0 || page >= DISPLAY_PAGES) return;
 for (int col = 0; col < 8; col++){
    int px = x + col;
    if (page<0 || page >= DISPLAY_WIDTH) continue;
    framebuffer[page * DISPLAY_WIDTH + px] = font8x8[idx][col];
 }

}

static void draw_text(int x, int y, const char *text) {
    int cursor_x = x;
    while (*text) {
        if (cursor_x + 8 > DISPLAY_WIDTH)
        break;
        draw_char(cursor_x, y, *text);
        cursor_x += 8;
        text++;
    }
}

void display_show_idle(int sessions_today) {
    display_clear();
    char buf[32];
    draw_text(0, 0, buf);
    snprintf(buf, sizeof(buf), "%d done today", sessions_today);
    draw_text(0, 16, buf);
    display_refresh();
}

void display_show_session_length(int seconds) {
    display_clear();
    char buf[32];
    int minutes = seconds / 60;
    snprintf(buf, sizeof(buf), "Length: %d min", minutes);
    draw_text(0, 0, buf);
    draw_text(0, 16, "Press to Start");
    display_refresh();
}

void display_show_break(int seconds_remaining) {
    display_clear();
    char buf[32];
    int minutes = seconds_remaining / 60;
    int secs = seconds_remaining % 60;
    snprintf(buf, sizeof(buf), "%02d:%02d", minutes, secs);
    draw_text(48, 12, buf);
    display_refresh();
}

void display_show_session_complete(int sessions_today) {
    display_clear();
    draw_text(0, 0, "session done!");
    char buf[32];
    snprintf(buf, sizeof(buf), "%d sessions today", sessions_today);
    draw_text(0, 16, buf);
    display_refresh();
}

void display_show_hydration_reminder(void) {
    display_clear();
    draw_text(0, 0, "drank yo watah init");
    draw_text(0, 16, "Hydwate yo self");
    display_refresh();
}
void display_show_low_battery(void) {
    display_clear();
    draw_text(0, 12, "Low battery");
    display_refresh();
}
void display_show_timer(int seconds_remaining){
 display_clear();
 char buf[32];
 int minutes = seconds_remaining / 60;
 int secs = seconds_remaining % 60;
 snprintf(buf, sizeof(buf), "%02d:%02d", minutes, secs);
 draw_text(48, 12, buf);
 display_refresh();
}

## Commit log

2026-06-15 Added Schematic, and updated README
    [Keychain.kicad_sch]
2026-06-19 Written code, built some of it.
    [partitions.csv]
2026-06-19 Enhance README with technical details and assembly guide
    Added detailed technical specifications and assembly instructions for the keychain project, including components, power subsystem, audio setup, and PCB design.
2026-06-19 Add BOM table to README
    Added a table for the Bill of Materials (BOM) section in the README.
2026-06-19 Update BOM in README with component details
    Added detailed BOM with item names, quantities, prices, and URLs for components.
2026-06-19 Bug Crushed and built
    [SSD1306_OLED-0.91-128x32.step, ssd1306-0-91.stl]
2026-06-19 Update README with assembly and design notes
    Added assembly instructions and design notes to README.
2026-06-19 Convert BOM file to CSV format
    Updated the BOM format from tab-separated to CSV format.
    [bom.csv]
2026-06-19 Revise README for improved clarity and organization
    Updated README.md to enhance clarity and structure, including sections on functions, technical details, and assembly instructions.
